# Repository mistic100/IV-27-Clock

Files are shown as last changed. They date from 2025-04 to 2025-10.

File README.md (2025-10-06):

# IV-27 VFD Clock



[More photos on my website](https://photos.strangeplanet.fr/index.php?/category/256-iv_27_vfd_clock)

## Features

- Current time/date (NTP or RTC)
- Temperature + Humidity
- Select displayed info with a rotary knob
- Display simple messages from Home Assistant
- Auto off during night + occupancy sensor from Home Assistant
- Light effects

## Operation

The IV-27 tube is a multiplexed display: it has 8 inputs for each part of a digit (7 segments + dot) and 14 grids to select which digit to display. Thats 22 pins to drive at 25 volts.

For this job we use the MAX6921 IC which has 20 high-voltage outputs (I choose to not use the first grid which only has symbols nor the right-most digit).
The MAX6921 is a simple serial to parallel converter: to send a data frame we have to put `DIN` low or high, ticking `CLK` for each value, once the 20 bits are send, ticking `LOAD` sets the outputs accordingly.

Because the display is multiplexed we have to repetitively set each digit in an infinite loop.

## Bill of materials

- IV-27 VFD tube
- MAX6921 serial-interface
- SOP28 to DIP28 adapter
- Seeed Studio Xiao ESP32C3 MCU
- (optional) BME280 ambient sensor
- (optional) DS3231 RTC
- MT3608 or XL6009 boost converter (25V)
- Mini560 or LM2596 buck converter (3.3V)
- 2x 130mm LED "noodle"
	- NPN transitor and resistors (to drive the lights)
- rotary encoder with push action
	- 2x 100nF capacitors (between GND and the encoder A and B pins)

## Schematics

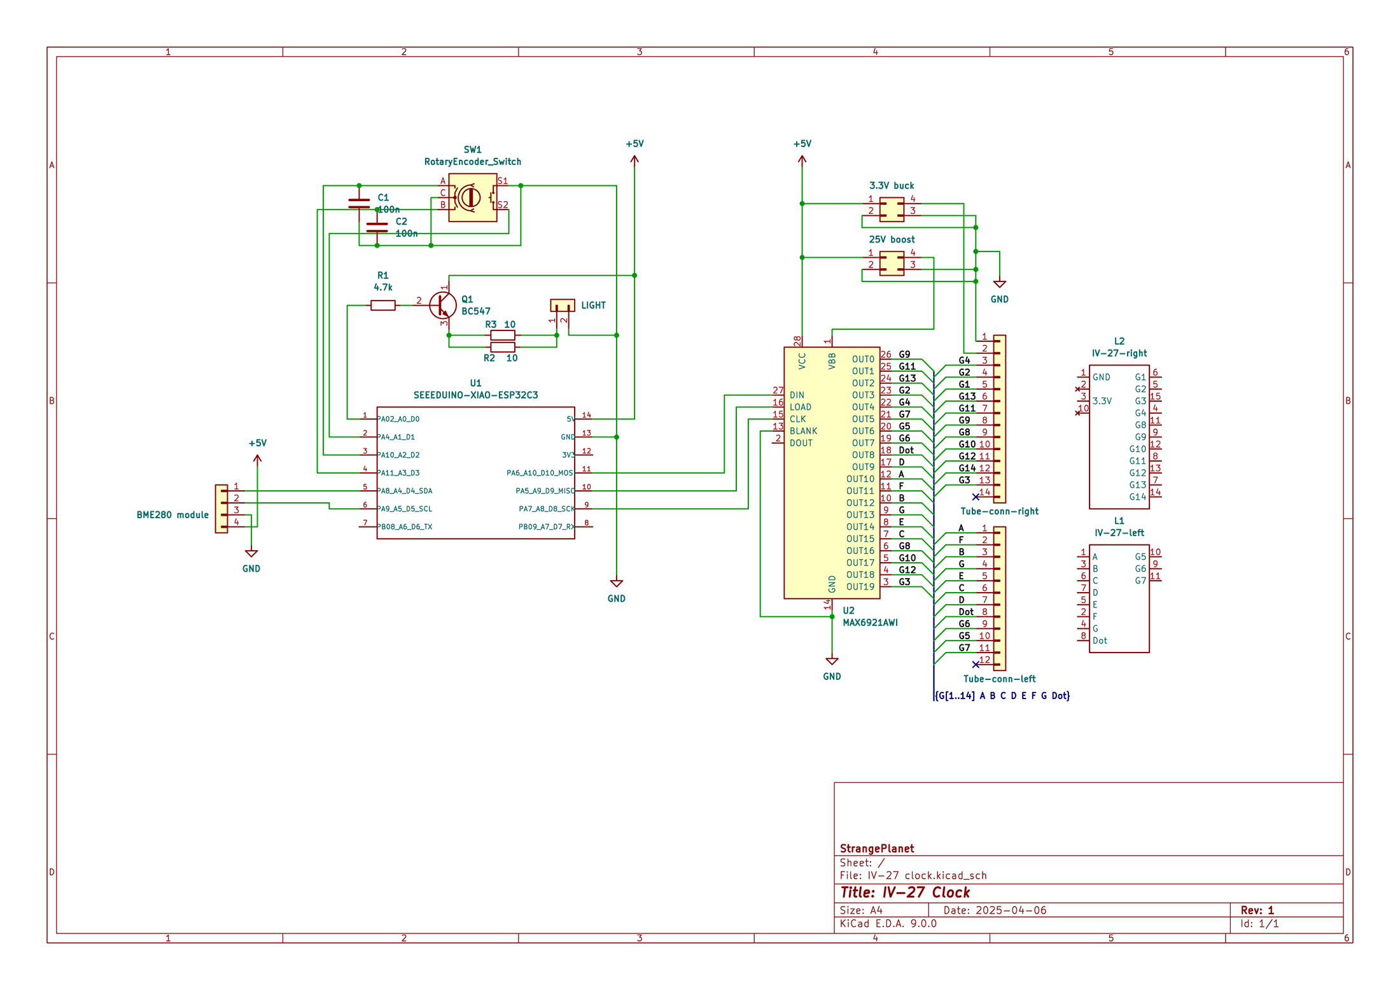
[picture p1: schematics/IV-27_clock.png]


## Interactions

In display mode:
- single click: toggle on-off
- rotate left or right: switch between time/date/temperature/message
- long click: enter menu

In menu mode:
- rotate left or right: select menu item
- single click: select menu item

In setting:
- rotate left or right: change value
- single click: next element/save
- long click: previous element

Menu content :
- SET DATE (RTC mode only)
- SET TIME (RTC mode only)
- DATE FORMAT: switch between `YYYY-MM-DD` and `DD month` date format
- SET LIGHT: configure lights effect and brightness
- SET DAYTIME: configure start & end time for auto off feature
- TEMP OFFSET: configure the offset of the measured temperature
- MESS TIMEOUT: configure the delay after which the message is displayed
- BACK

## Configuration

### Home Assistant

Add a custom binary sensor with the following attributes:
- `at_home: "{{ states('zone.home') | int(default=0) > 0 }}"`
- `message`: the message to display (only letters, numbers, `.` and `-` symbols)

**Example (extracting next due item from a todo list):**
```yaml
template:
  - triggers:
      - trigger: state
        entity_id:
          - todo.my_list
          - zone.home
        # scheduler to handle item status change
      - trigger: time_pattern
        minutes: "/5"
    action:
      - service: todo.get_items
        data:
          status: needs_action
        target:
          entity_id: todo.my_list
        response_variable: items
    binary_sensor:
      - unique_id: data_for_iv27_clock
        state: true
        attributes:
          at_home: "{{ states('zone.home') | int(default=0) > 0 }}"
          message: >
            {% set tdate = (now().date() + timedelta(days=1)) | string %}
            {{ items['todo.my_list']['items'] 
              | selectattr('due', 'defined') | selectattr('due', 'lt', tdate) 
              | map(attribute='summary') | first() | truncate(255) }}
```

### Firmware

Copy `secrets.tpl.h` into `secrets.h` and fill the values.

- `HA_TOKEN`: go to your HA profile page, then Security, and create a new Long lived token at the bottom of the page (keep the `Bearer ` prefix)
- `HA_URL`: fill in your HA hostname
- `HA_SENSOR`: set the id of the sensor created above
- `OTA_PASS`: choose a password to secure the Wifi OTA update

Copy `upload_params.tpl.ini` into `upload_params.ini` and fill the OTA password.

----

In `constants.hpp` you can also configure:

- `USE_NTP`: use Network Time Prototal, comment to use RTC instead
- `USE_WIFI_OTA`: comment to disable the Wifi OTA
- `USE_TEMP_SENSOR`: comment to disable the ambient sensor
- `USE_HA_MESSAGE`: comment to disable the message display from HA
- `USE_HA_OCCUPANCY`: comment to disable occupancy info from HA
- `TIMEZONE`: timezone for NTP ([check available TZ](https://github.com/esp8266/Arduino/blob/master/cores/esp8266/TZ.h))
- `DRIVER_DIN`, `DRIVER_CLK`, `DRIVER_LOAD`: MCU pins to the MAX6921
- `ENCODER_A`, `ENCODER_B`, `ENCODER_SW`: MCU pins to the rotary encoder
- `LIGHT_P`: MCU pins to the lights
- `GRID`, `SEGMENTS`: MAX6921 pins to the display

## Resources

- https://www.instructables.com/VFD-Alarm-Clock/
- https://www.barbouri.com/2020/07/04/iv-27-icetube-clock-project/

## License

Creative Commons 3.0 BY-SA

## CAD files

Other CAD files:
model/sop28-adapter.SLDASM
model/_IV-27-Clock.SLDASM
model/VALVe_v6.SLDPRT
model/LED filament 130mm.SLDPRT
model/DS1024-2x8RF1.SLDPRT
model/Pin Header 1x14 TH Pitch 2.54mm.SLDPRT
model/MINI560_light.SLDPRT
model/sop28-adapter-board.SLDPRT
model/DS1024-2x6RF1.SLDPRT
model/BME280.SLDPRT
model/Seeed Studio XIAO-ESP32-C3.SLDPRT
model/IV-27 tube.SLDPRT
model/SOP28.SLDPRT
model/copper-corner.SLDPRT
model/EC11 Rotary Encoder.SLDPRT
model/XL6009.SLDPRT
model/box.SLDPRT
model/DOTTED PCB 5 7 CM.SLDPRT
model/M3x5.SLDPRT

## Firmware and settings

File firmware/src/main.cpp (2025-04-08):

#include <Arduino.h>
#include <ESPRotary.h>
#include <Button2.h>
#include <Wire.h>
#include "Settings.hpp"
#include "Display.hpp"
#include "Light.hpp"
#include "Ui.hpp"
#include "Controller.hpp"
#include "constants.hpp"

#ifdef USE_WIFI
#include <WiFi.h>
static const char *TAG_WIFI = "WIFI";
#endif
#ifdef USE_WIFI_OTA
#include <ArduinoOTA.h>
#endif

ESPRotary rotaryEncoder;
Button2 button;

void setup()
{
    Serial.begin(115200);

    SETTINGS.begin();

#ifdef USE_WIFI
    WiFi.mode(WIFI_STA);
    WiFi.begin(WIFI_SSID, WIFI_PASS);

    while (WiFi.status() != WL_CONNECTED)
    {
        ESP_LOGI(TAG_WIFI, "Wait Wifi");
        delay(500);
    }

    ESP_LOGI(TAG_WIFI, "%s", WiFi.localIP().toString());
#endif

#ifdef USE_WIFI_OTA
    ArduinoOTA.setRebootOnSuccess(true);
    ArduinoOTA.setHostname(HOSTNAME);
    ArduinoOTA.setMdnsEnabled(true);
    ArduinoOTA.setPassword(OTA_PASS.c_str());
    ArduinoOTA.begin();

    ArduinoOTA.onStart([]() {
        CTRL.off(true);
    });
#endif

    Wire.begin();
    DISP.begin();
    LIGHT.begin();
    CTRL.begin();
    button.begin(ENCODER_SW);
    rotaryEncoder.begin(ENCODER_A, ENCODER_B, 4);

    button.setClickHandler([](Button2 &btn) { 
        UI.click();
    });
    button.setLongClickHandler([](Button2 &btn) { 
        UI.longClick();
    });
    rotaryEncoder.setLeftRotationHandler([](ESPRotary &r) { 
        UI.down();
    });
    rotaryEncoder.setRightRotationHandler([](ESPRotary &r) {
        UI.up();
    });
}

void loop()
{
#ifdef USE_WIFI_OTA
    ArduinoOTA.handle();
#endif
    button.loop();
    rotaryEncoder.loop();
    CTRL.loop();
    LIGHT.loop();
    DISP.loop();
}

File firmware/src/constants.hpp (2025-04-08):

#pragma once

#include "secrets.hpp"

// enable NTP (comment to use RTC)
#define USE_NTP
// enable Wifi OTA
#define USE_WIFI_OTA
// enable BME280 ambient sensor
#define USE_TEMP_SENSOR
// enable message display from Home Assistant
#define USE_HA_MESSAGE
// enable turn off from Home Assistant home occupancy
#define USE_HA_OCCUPANCY

#if defined(USE_HA_MESSAGE) || defined(USE_HA_OCCUPANCY)
#define USE_HA
#endif

#if defined(USE_NTP) || defined(USE_WIFI_OTA) || defined(USE_HA)
#define USE_WIFI
#endif

#ifndef USE_NTP
#define USE_RTC
#endif

#define DRIVER_DIN D10
#define DRIVER_CLK D8
#define DRIVER_LOAD D9

#define LIGHT_P D0

#define ENCODER_A D2
#define ENCODER_B D3
#define ENCODER_SW D1

#ifdef USE_NTP
// https://github.com/esp8266/Arduino/blob/master/cores/esp8266/TZ.h
#define TIMEZONE "CET-1CEST,M3.5.0,M10.5.0/3"
#endif
#ifdef USE_WIFI_OTA
#define HOSTNAME "iv27-clock"
#endif
#ifdef USE_HA
#define HA_UPDATE_INTERVAL_S 60
#endif
#ifdef USE_TEMP_SENSOR
#define TEMP_UPDATE_INTERVAL_S 10
#endif

#define BLINK_INTERVAL_MS 300
#define SCROLL_INTERVAL_MS 150

#define NUM_GRIDS 12
#define NUM_OUTS 20

uint8_t GRID[NUM_GRIDS] = {
    // 14 unused
    2,  // 13
    18, // 12
    1,  // 11
    17, // 10
    0,  // 9
    16, // 8
    5,  // 7
    7,  // 6
    6,  // 5
    4,  // 4
    19, // 3
    3,  // 2
    // 1 unused
};

uint8_t SEGMENTS[8] = {
    10, // A
    12, // B
    15, // C
    9,  // D
    14, // E
    11, // F
    13, // G
    8,  // Pt
};

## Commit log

2025-03-18 Dispplay temperature/humidity
2025-03-21 Conditions Wifi & ambient sensor
2025-04-06 Add schematics
    [IV-27 clock.kicad_sch]
2025-04-06 Add SolidWorks model
    [BME280.SLDPRT, DOTTED PCB 5 7 CM.SLDPRT, DS1024-2x6RF1.SLDPRT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]
2025-04-08 update schematics
    [IV-27 clock.kicad_sch]
